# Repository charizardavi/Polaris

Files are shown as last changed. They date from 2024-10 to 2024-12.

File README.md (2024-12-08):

# Polaris Flight Computer

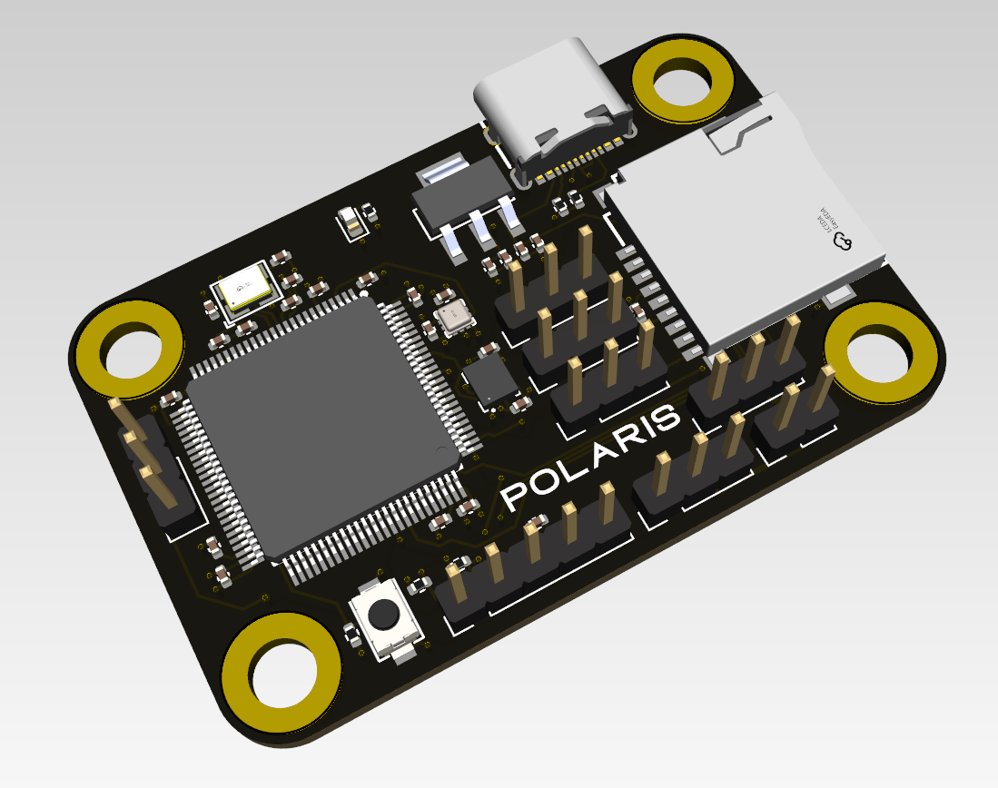
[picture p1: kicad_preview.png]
pcb image


System clock: 480mhz

Interfaces:
- ST-Link
- USB OTG (type C)
- 5x Servo/BLDC Motor output

currently using:
- STM32H743ZIT6 MCU
- LSM6DSO 6-axis IMU
- BMP388 barometer
- SDMMC interface on MCU to write to micro SD card

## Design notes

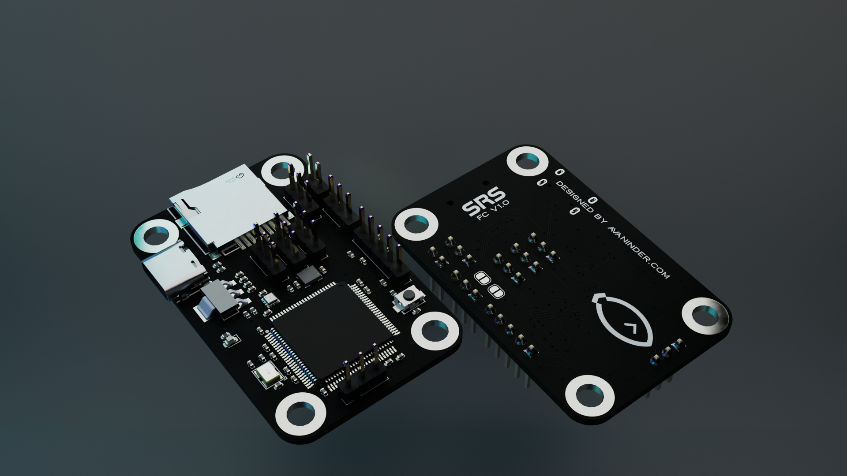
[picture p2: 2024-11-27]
render_1.png

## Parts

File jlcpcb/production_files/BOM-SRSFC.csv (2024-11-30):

Comment | Designator | Footprint | LCSC
20pF | C2,C3 | C_0402_1005Metric | C107000
~ | U1 | QFP-100_L14.0-W14.0-P0.50-LS16.0-BL | C114409
25MHz | X1 | OSC-SMD_4P-L3.2-W2.5-BL | C13740
1uF | C1,C5 | C_0402_1005Metric | C14445
2.2uF | C10,C12 | C_0402_1005Metric | C170151
100 | R2 | R_0402_1005Metric | C25076
10k | R1,R5,R6 | R_0402_1005Metric | C25744
5.1k | R3,R4 | R_0402_1005Metric | C25905
~ | USB1 | USB-C-SMD_TYPE-C-6PIN-2MD-073 | C2765186
~ | U2 | LGA-14L_L3.0-W2.5-P0.50-TL | C2829074
~ | U5 | SOT-223-4_L6.5-W3.5-P2.30-LS7.0-BR | C347222
4.7uF | C4 | C_0402_1005Metric | C368809
~ | CARD1 | TF-SMD_TF-PUSH | C393941
100nF | C11,C13,C14,C15,C16,C17,C23,C25,C26,C27,C28,C6,C7,C8,C9 | C_0402_1005Metric | C60474
~ | SW1 | SW-SMD_L3.9-W3.0-P4.45 | C720477
10uF | C22,C24 | C_0402_1005Metric | C77000
~ | U6 | SENSORM-SMD_BMP388 | C779278
green_led | D1 | LED_0603_1608Metric | C965799

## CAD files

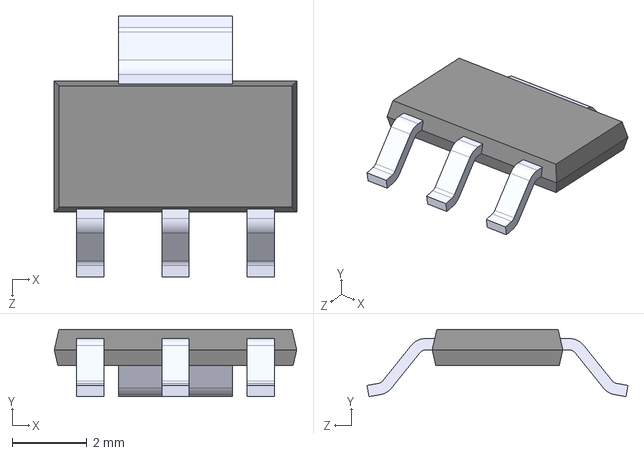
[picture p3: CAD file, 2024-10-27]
parts_lib/AMS1117-3.3/AMS1117-3.3.STEP
6.50 x 1.80 x 7.00 mm

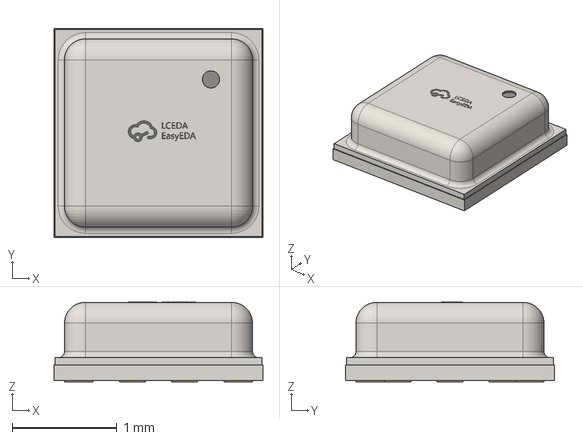
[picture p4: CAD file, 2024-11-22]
parts_lib/BMP388/BMP388.step
2.00 x 2.00 x 0.761 mm

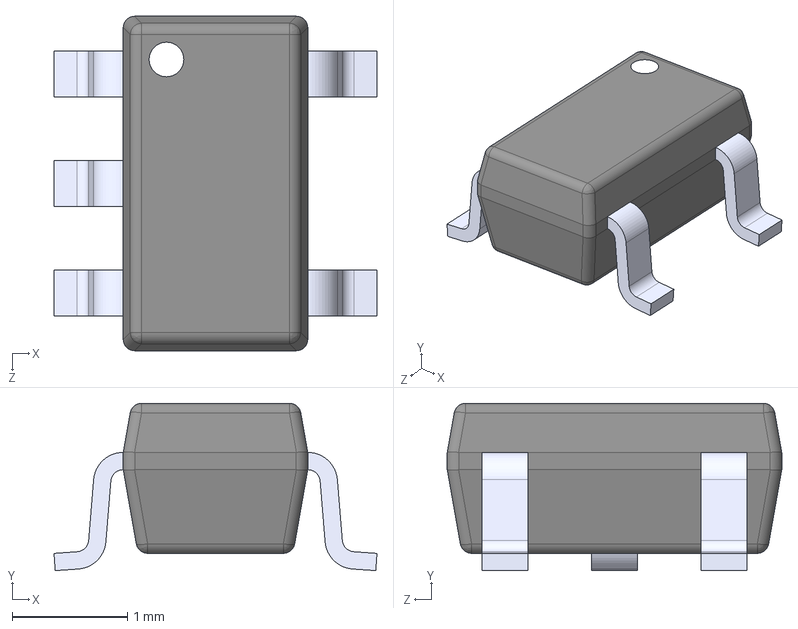
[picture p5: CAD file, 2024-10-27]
parts_lib/LP5907MFX-1.8/LP5907MFX-1.8.STEP
2.80 x 1.45 x 2.90 mm

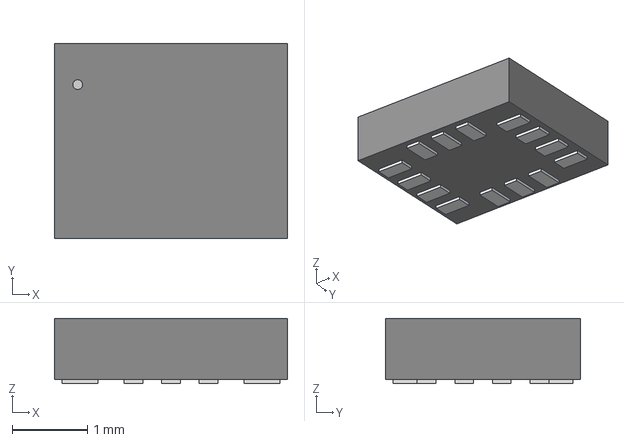
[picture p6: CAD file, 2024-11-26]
parts_lib/LSM6DSOWTR/LSM6DSOWTR.step
3.10 x 2.59 x 0.866 mm

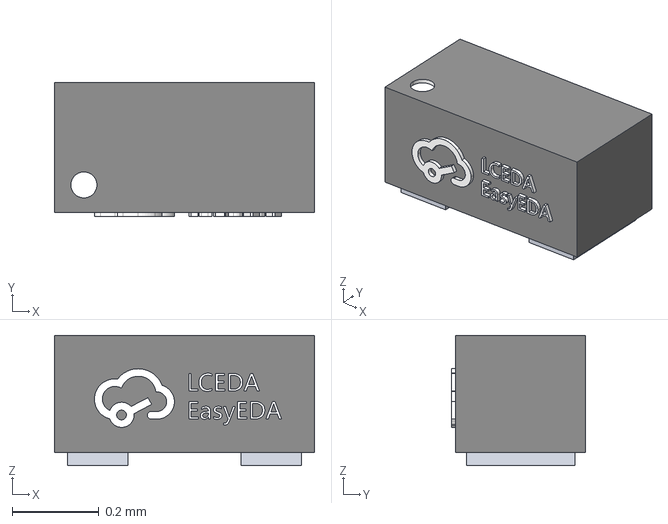
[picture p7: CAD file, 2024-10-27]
parts_lib/PESD3V3Z1BSF/PESD3V3Z1BSF.step
0.6 x 0.31 x 0.3 mm

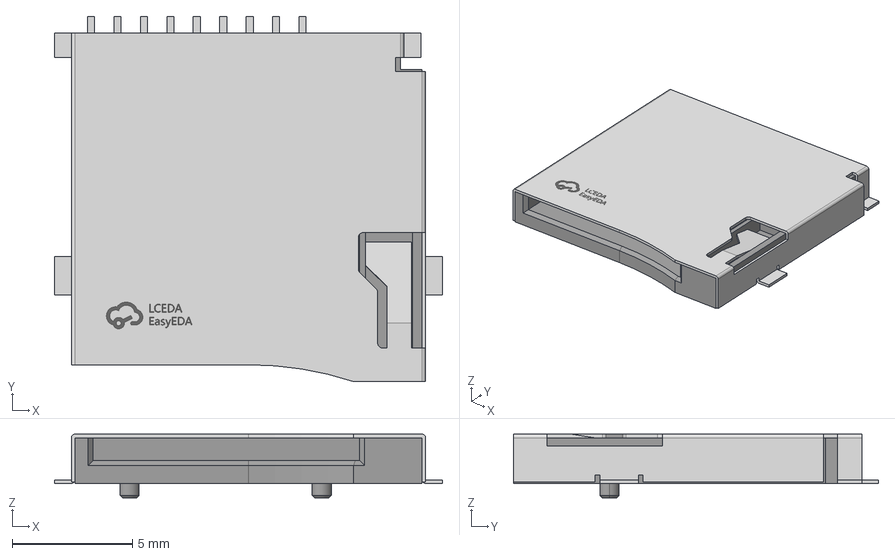
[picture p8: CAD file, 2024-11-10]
parts_lib/SD_CARD_READER/SD_CARD_READER.step
16.2 x 15.2 x 2.65 mm

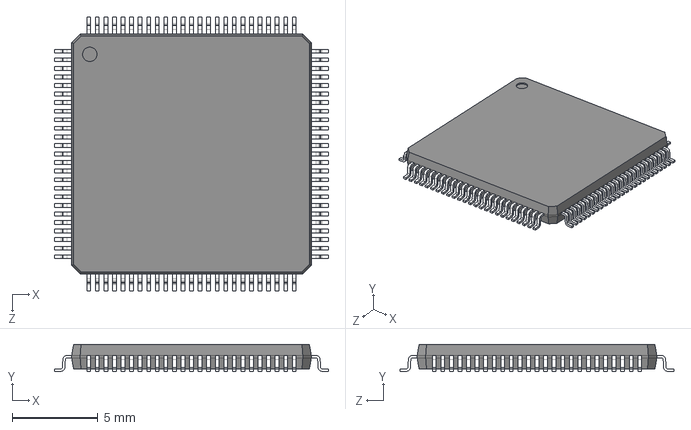
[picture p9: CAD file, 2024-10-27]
parts_lib/STM32H750VBT6TR/STM32H750VBT6TR.STEP
16.0 x 1.60 x 16.0 mm

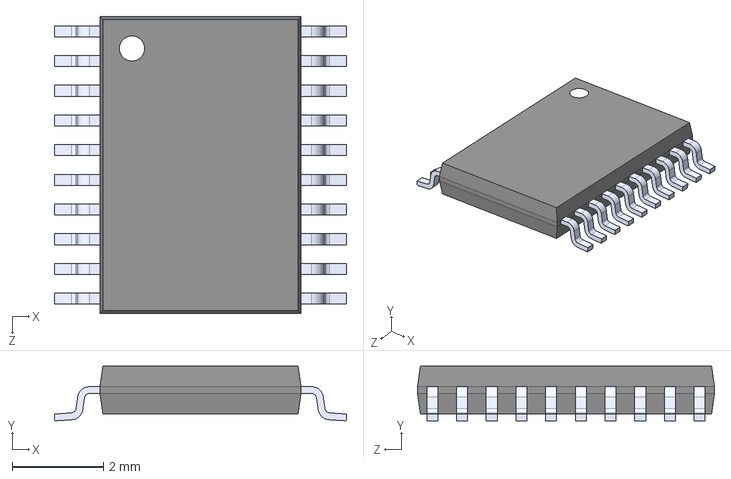
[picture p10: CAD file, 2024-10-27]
parts_lib/TXS0108EPWR/TXS0108EPWR.STEP
6.40 x 1.20 x 6.50 mm

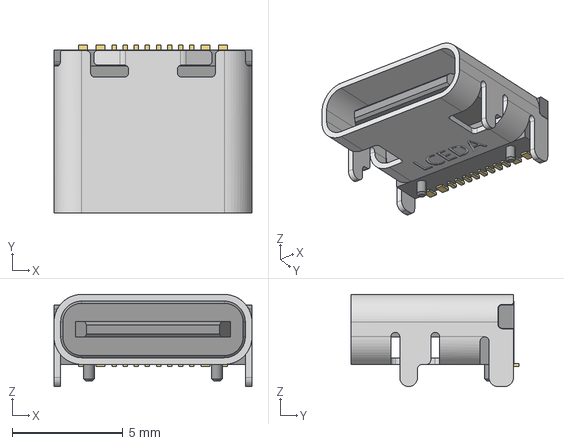
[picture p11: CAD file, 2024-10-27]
parts_lib/TYPE-C-16/TYPE-C-16.step
8.94 x 7.58 x 4.16 mm

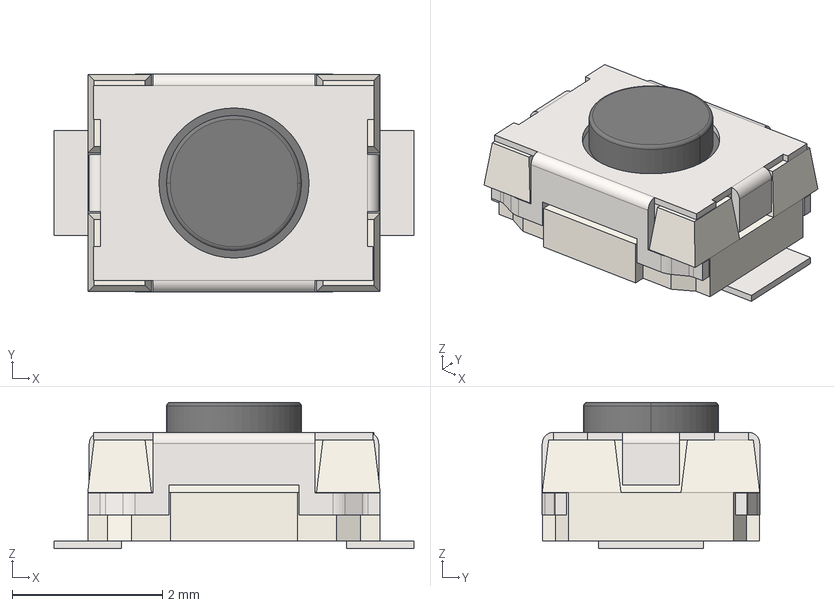
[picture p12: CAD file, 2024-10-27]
parts_lib/XUNPU-TS-1088-AR02016/XUNPU-TS-1088-AR02016.step
4.80 x 2.90 x 1.95 mm

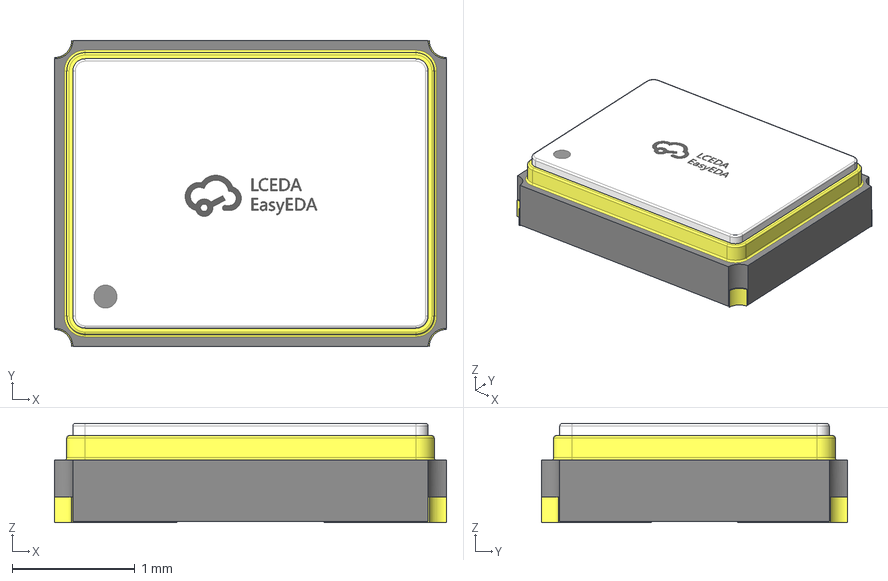
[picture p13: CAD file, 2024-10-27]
parts_lib/X322525MSB4SI/X322525MSB4SI.step
3.20 x 2.50 x 0.811 mm

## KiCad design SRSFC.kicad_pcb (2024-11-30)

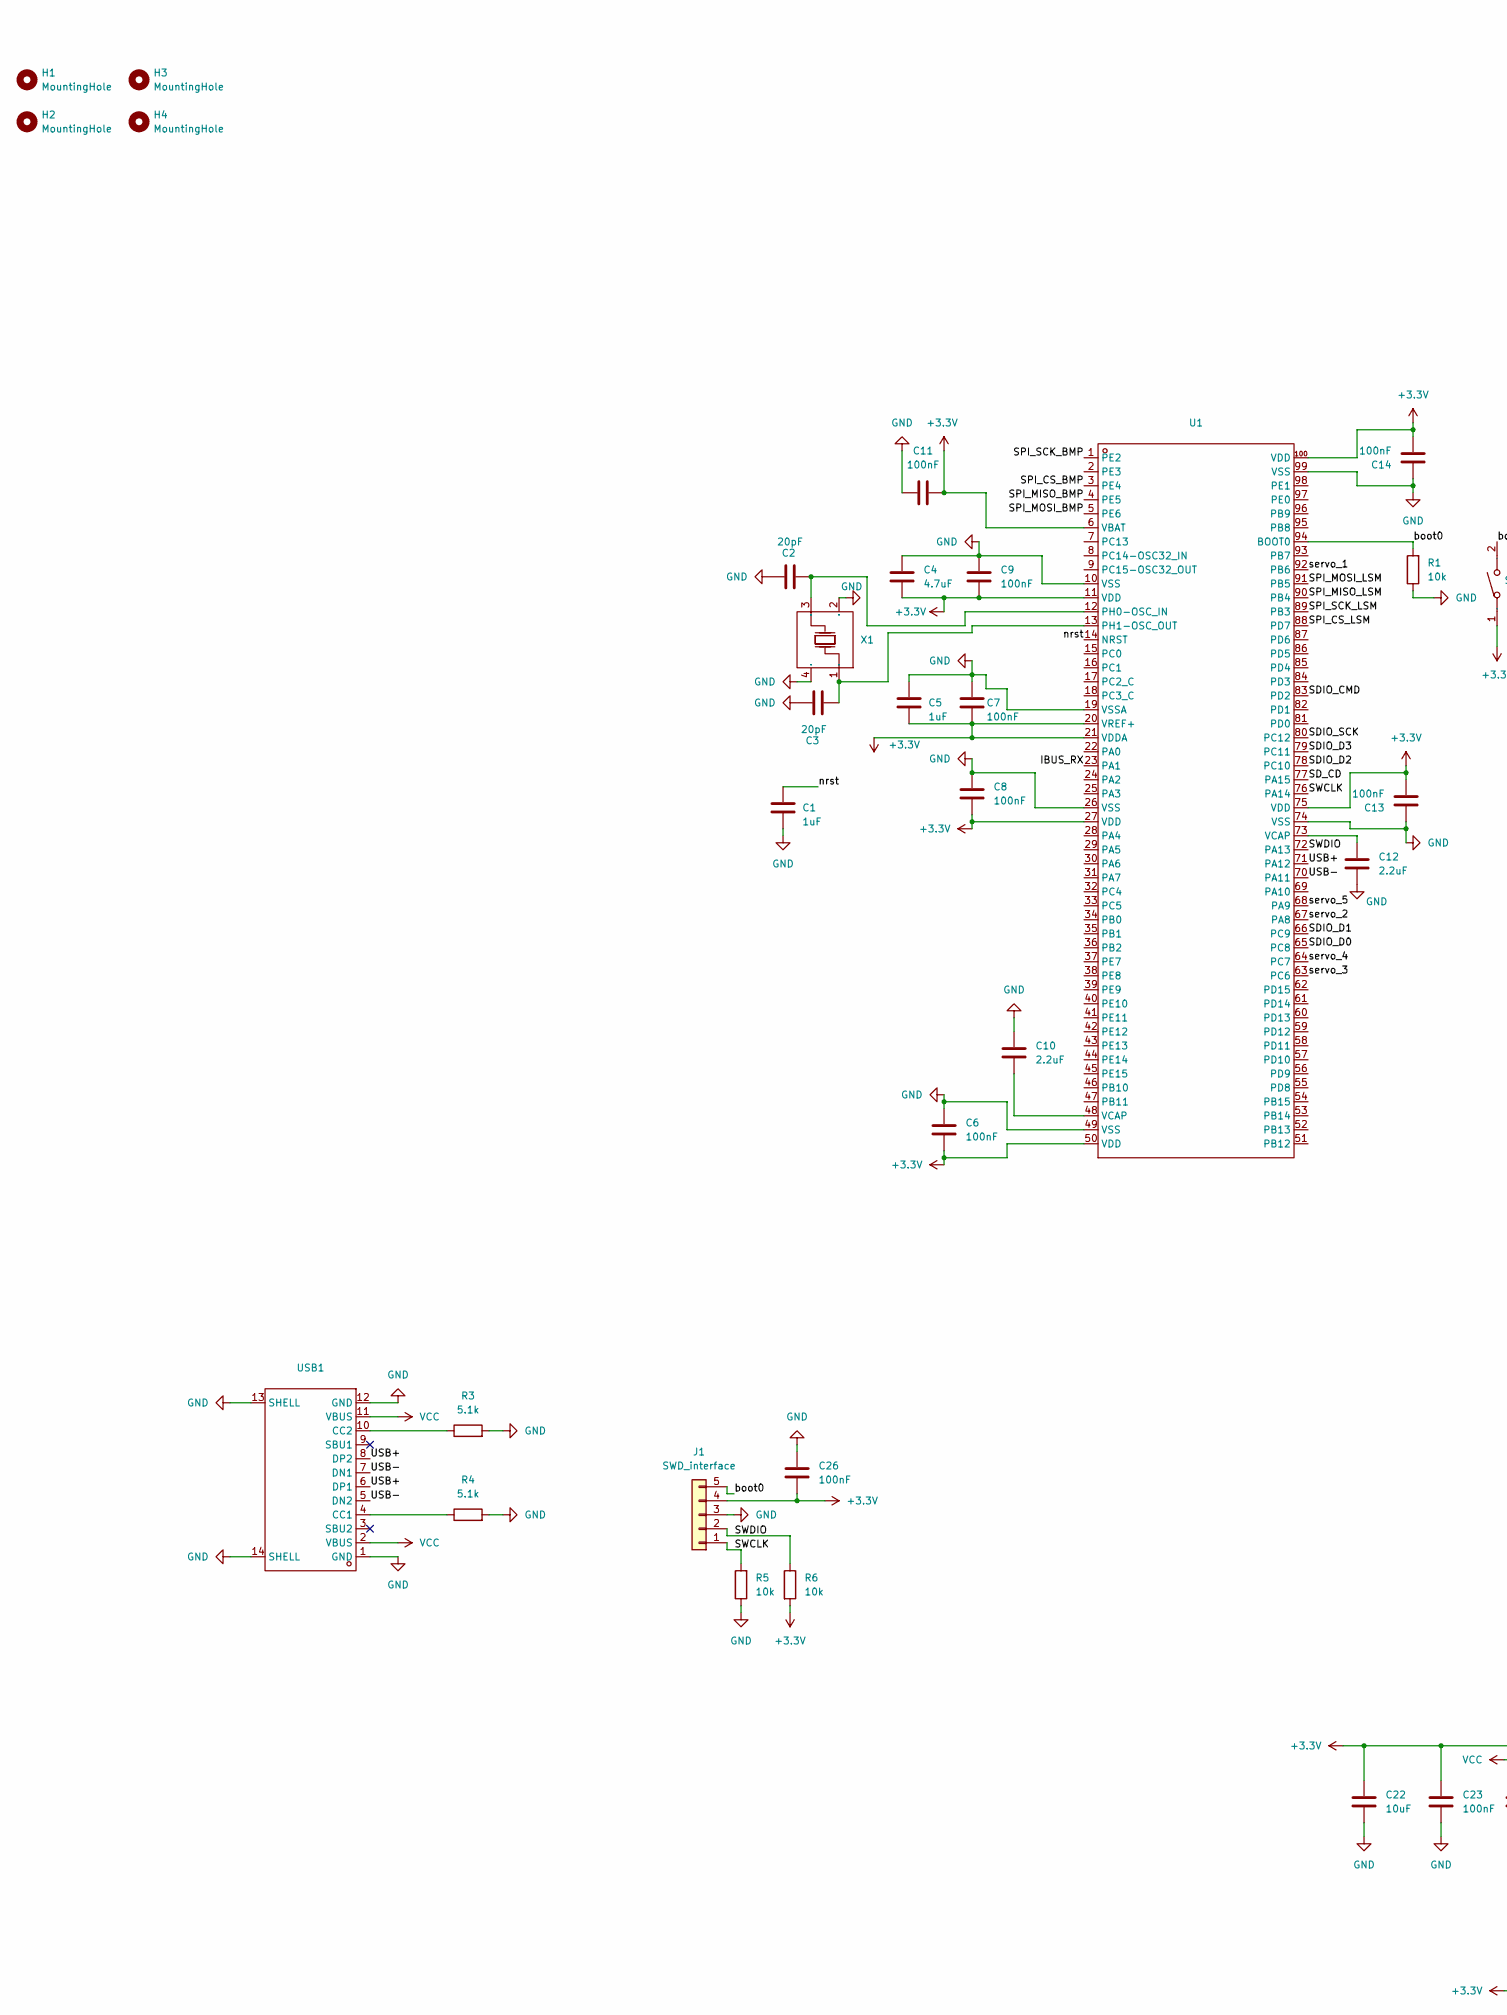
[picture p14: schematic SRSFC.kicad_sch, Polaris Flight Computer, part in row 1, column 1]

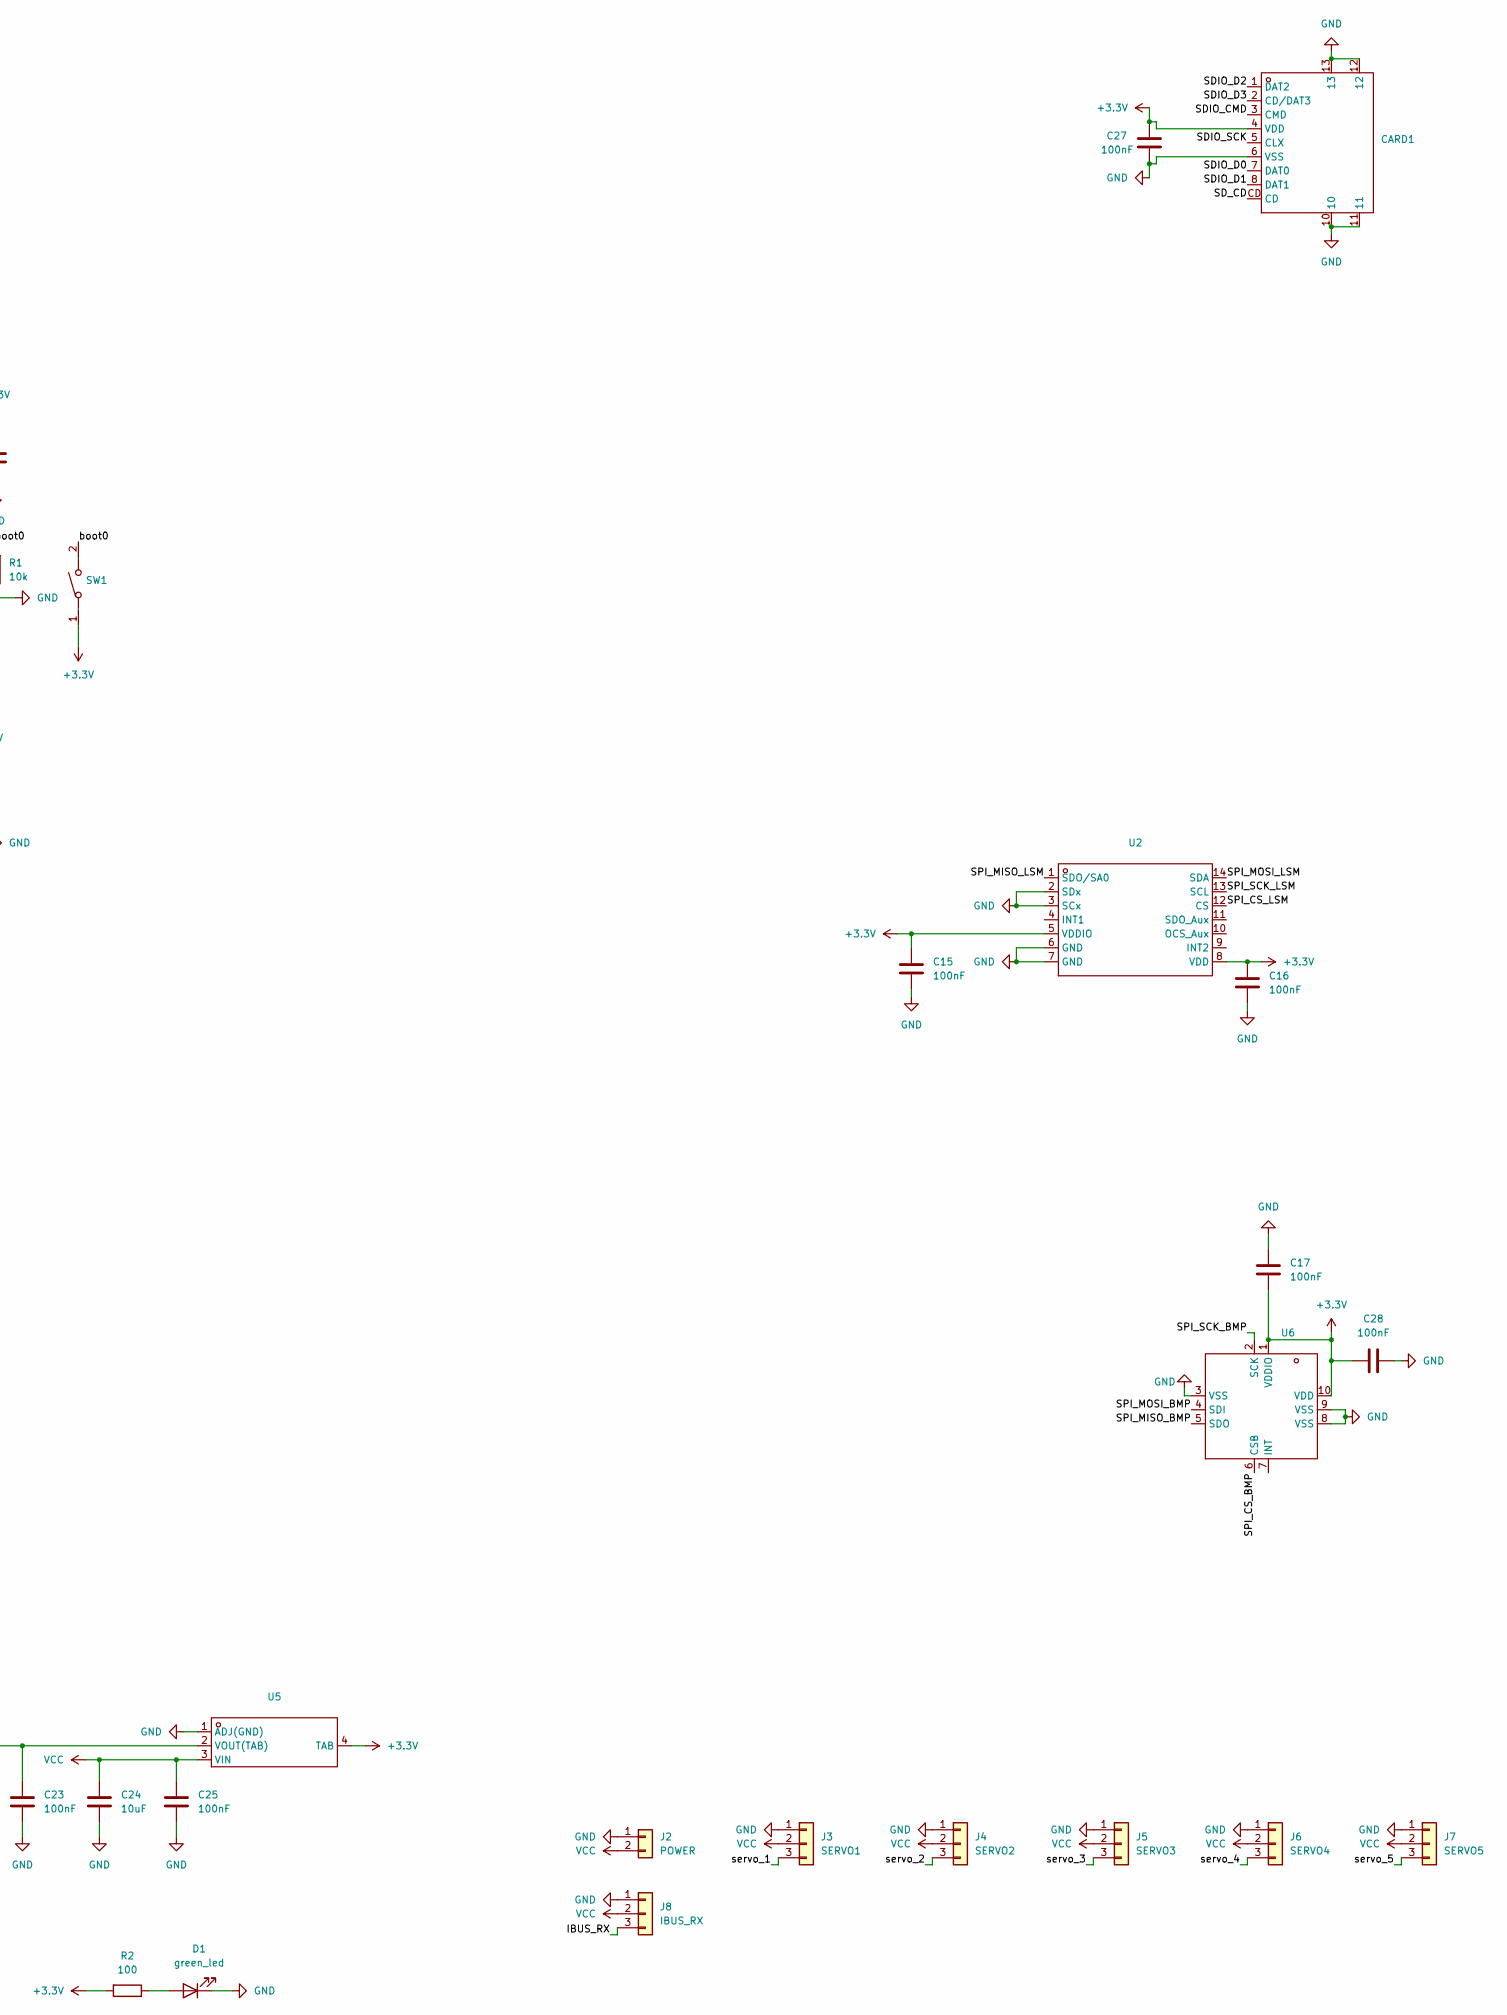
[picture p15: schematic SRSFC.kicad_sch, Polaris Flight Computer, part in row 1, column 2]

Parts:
C1, C5: 1uF; C_0402_1005Metric
C2, C3: 20pF; C_0402_1005Metric
C4: 4.7uF; C_0402_1005Metric
C6, C7, C8, C9, C11, C13, C14, C15, C16, C17, C23, C25, C26, C27, C28: 100nF; C_0402_1005Metric
C10, C12: 2.2uF; C_0402_1005Metric
C22, C24: 10uF; C_0402_1005Metric
CARD1: TF-SMD_TF-PUSH; Manufacturer Part TF PUSH; LCSC Part Name 自弹式 MicroSD卡(TF卡) 卡座
D1: green_led; LED_0603_1608Metric
H1, H2, H3, H4: MountingHole; MountingHole_4.3mm_M4_DIN965_Pad
J1: SWD_interface; PinHeader_1x05_P2.54mm_Vertical
J2: POWER; PinHeader_1x02_P2.54mm_Vertical
J3: SERVO1; PinHeader_1x03_P2.54mm_Vertical
J4: SERVO2; PinHeader_1x03_P2.54mm_Vertical
J5: SERVO3; PinHeader_1x03_P2.54mm_Vertical
J6: SERVO4; PinHeader_1x03_P2.54mm_Vertical
J7: SERVO5; PinHeader_1x03_P2.54mm_Vertical
J8: IBUS_RX; PinHeader_1x03_P2.54mm_Vertical
R1, R5, R6: 10k; R_0402_1005Metric
R2: 100; R_0402_1005Metric
R3, R4: 5.1k; R_0402_1005Metric
SW1: SW-SMD_L3.9-W3.0-P4.45; Manufacturer Part TS-1088-AR02016; LCSC Part Name 4*3*2mm 立贴 轻触开关
U1: QFP-100_L14.0-W14.0-P0.50-LS16.0-BL; Manufacturer Part STM32H750VBT6TR; LCSC Part Name 带DSP和DP-FPU的高性能ARM Cortex-M7 MCU，具有128 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
U2: LGA-14L_L3.0-W2.5-P0.50-TL; Manufacturer Part LSM6DSOWTR; LCSC Part Name LSM6DSOWTR
U5: SOT-223-4_L6.5-W3.5-P2.30-LS7.0-BR; Manufacturer Part AMS1117-3.3; LCSC Part Name 输出:3.3V 电流:1A 耐压:12V
U6: SENSORM-SMD_BMP388; Manufacturer Part BMP388; LCSC Part Name BMP388
USB1: USB-C-SMD_TYPE-C-6PIN-2MD-073; Manufacturer Part TYPE-C 16PIN 2MD(073); LCSC Part Name Type-C 母 卧贴
X1: 25MHz; OSC-SMD_4P-L3.2-W2.5-BL; Manufacturer Part X322525MSB4SI; LCSC Part Name 25MHz ±10ppm 20pF

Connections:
+3.3V: C4.2, C5.1, C6.1, C7.1, C8.1, C9.1, C11.2, C13.1, C14.1, C15.1, C16.2, C17.1, C22.1, C23.1, C26.1, C27.2, C28.1, CARD1.4 (VDD), J1.4, R2.2, R6.2, SW1.1, U1.6 (VBAT), U1.11 (VDD), U1.20 (VREF+), U1.21 (VDDA), U1.27 (VDD), U1.50 (VDD), U1.75 (VDD), U1.100 (VDD), U2.5 (VDDIO), U2.8 (VDD), U5.2 (VOUT(TAB)), U5.4 (TAB), U6.1 (VDDIO), U6.10 (VDD)
/IBUS_RX: J8.3, U1.23 (PA1)
/SDIO_CMD: CARD1.3 (CMD), U1.83 (PD2)
/SDIO_D0: CARD1.7 (DAT0), U1.65 (PC8)
/SDIO_D1: CARD1.8 (DAT1), U1.66 (PC9)
/SDIO_D2: CARD1.1 (DAT2), U1.78 (PC10)
/SDIO_D3: CARD1.2 (CD/DAT3), U1.79 (PC11)
/SDIO_SCK: CARD1.5 (CLX), U1.80 (PC12)
/SD_CD: CARD1.CD, U1.77 (PA15)
/SPI_CS_BMP: U1.3 (PE4), U6.6 (CSB)
/SPI_CS_LSM: U1.88 (PD7), U2.12 (CS)
/SPI_MISO_BMP: U1.4 (PE5), U6.5 (SDO)
/SPI_MISO_LSM: U1.90 (PB4), U2.1 (SDO/SA0)
/SPI_MOSI_BMP: U1.5 (PE6), U6.4 (SDI)
/SPI_MOSI_LSM: U1.91 (PB5), U2.14 (SDA)
/SPI_SCK_BMP: U1.1 (PE2), U6.2 (SCK)
/SPI_SCK_LSM: U1.89 (PB3), U2.13 (SCL)
/SWCLK: J1.1, R5.2, U1.76 (PA14)
/SWDIO: J1.2, R6.1, U1.72 (PA13)
/USB+: U1.71 (PA12), USB1.6 (DP1), USB1.8 (DP2)
/USB-: U1.70 (PA11), USB1.5 (DN2), USB1.7 (DN1)
/boot0: J1.5, R1.2, SW1.2, U1.94 (BOOT0)
/nrst: C1.2, U1.14 (NRST)
/servo_1: J3.3, U1.92 (PB6)
/servo_2: J4.3, U1.67 (PA8)
/servo_3: J5.3, U1.63 (PC6)
/servo_4: J6.3, U1.64 (PC7)
/servo_5: J7.3, U1.68 (PA9)
GND: C1.1, C2.2, C3.2, C4.1, C5.2, C6.2, C7.2, C8.2, C9.2, C10.2, C11.1, C12.2, C13.2, C14.2, C15.2, C16.1, C17.2, C22.2, C23.2, C24.2, C25.2, C26.2, C27.1, C28.2, CARD1.6 (VSS), CARD1.10, CARD1.11, CARD1.12, CARD1.13, D1.1 (K), J1.3, J2.1, J3.1, J4.1, J5.1, J6.1, J7.1, J8.1, R1.1, R3.2, R4.2, R5.1, U1.10 (VSS), U1.19 (VSSA), U1.26 (VSS), U1.49 (VSS), U1.74 (VSS), U1.99 (VSS), U2.2 (SDx), U2.3 (SCx), U2.6 (GND), U2.7 (GND), U5.1 (ADJ(GND)), U6.3 (VSS), U6.8 (VSS), U6.9 (VSS), USB1.1 (GND), USB1.12 (GND), USB1.13 (SHELL), USB1.14 (SHELL), X1.2 (GND), X1.4 (GND)
unnamed: C10.1, U1.48 (VCAP)
unnamed: C12.1, U1.73 (VCAP)
unnamed: D1.2 (A), R2.1
unnamed: C2.1, U1.12 (PH0-OSC_IN), X1.3 (OSC2)
unnamed: C3.1, U1.13 (PH1-OSC_OUT), X1.1 (OSC1)
unnamed: R4.1, USB1.4 (CC1)
unnamed: R3.1, USB1.10 (CC2)
VCC: C24.1, C25.1, J2.2, J3.2, J4.2, J5.2, J6.2, J7.2, J8.2, U5.3 (VIN), USB1.2 (VBUS), USB1.11 (VBUS)

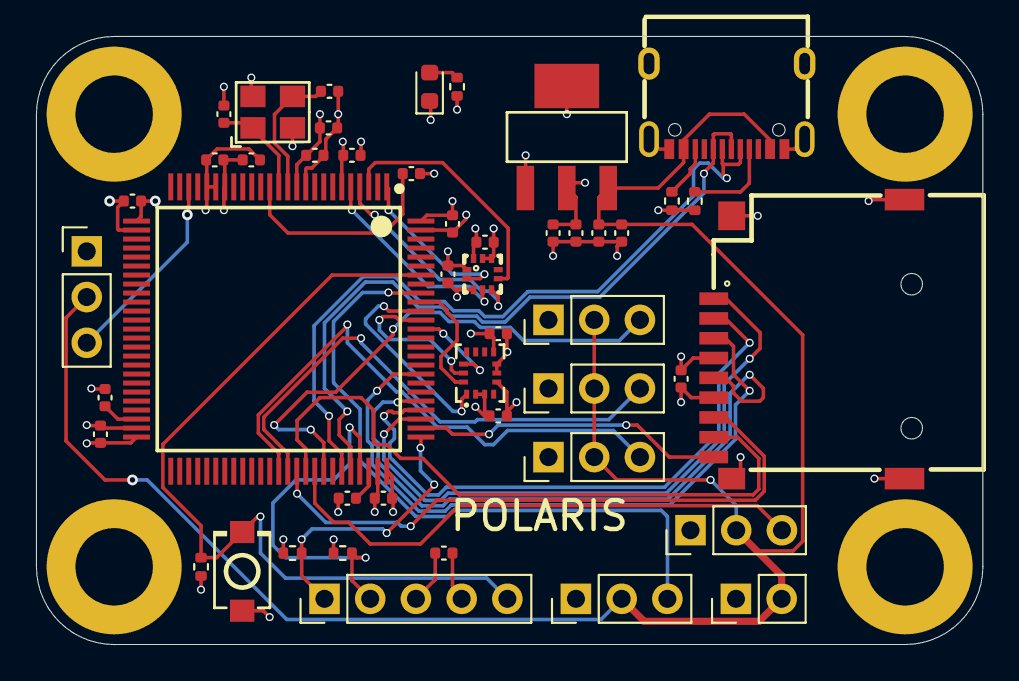
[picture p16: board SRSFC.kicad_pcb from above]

Board: 4 copper layers, 52.6 x 33.8 mm, 51 parts (0 on the bottom side), 37 nets.

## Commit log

2024-11-10 added BMP388
    [BMP388.step, SD_CARD_READER.step, SRSFC.kicad_pcb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]
2024-11-11 fixed some schema layout
    [SRSFC.kicad_sch]
2024-11-12 added servo connectors, schema done (probably)
    [SRSFC.kicad_pcb, SRSFC.kicad_sch]
2024-11-22 finished v1 (bad) layout)
    [BMP388.step, SRSFC.kicad_pcb, SRSFC.kicad_sch]
2024-11-22 good layout done, DRC passes
    [SRSFC.kicad_pcb]
2024-11-26 swapped ICM-20948 for LSM6DSO, added more TIM outputs
    [LSM6DSOWTR.step]
2024-11-26 added silkscreen, added UART interface
    [SRSFC.kicad_pcb, SRSFC.kicad_sch]
2024-11-27 changed sensors from i2c to SPI, fixed silkscreen
    [ICM-20948.step, SRSFC.kicad_pcb, SRSFC.kicad_sch]
2024-11-30 final commit before ordering
    [BOM-SRSFC.csv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]
